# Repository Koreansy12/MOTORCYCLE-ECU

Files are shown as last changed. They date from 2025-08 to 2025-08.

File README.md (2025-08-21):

# 🚀 FCU32 – Fuel Control Unit Based on ESP32

## 📌 Overview  
**FCU32** is an **experimental project** to build a simple **Fuel Control Unit (ECU)** using the **ESP32** platform.  
The main goal is to control a fuel injector based on standard engine sensors (RPM, MAP, TPS, O2, etc.).  

⚠️ **Disclaimer:**  
This project is still **theoretical**. The components and system have been designed and validated on paper, but **not yet fully realized in hardware**. It’s more like a **concept validation** and research documentation.

---

## 🛠️ Main Components
- **ESP32-S3** (main MCU)  
- **MAP + IAT + TPS Sensor** (from MAQS injector system)  
- **O2 Sensor** (Beat FI)  
- **RPM Pickup Sensor**  
- **Injector (Mio J)**  
- **Power Supply & MOSFET Driver** for injector control  

---

## 📊 Planned Features
- Fuel Injection Control via **lookup/VE table**  
- RPM sensing using **interrupts**  
- TPS & MAP input for engine load calculation  
- O2 sensor input for **closed-loop fuel correction** (planned)  
- UART/I2C communication with a **second ESP32-S3** (for display, logging, fuzzy logic)  
- Multitasking support using **FreeRTOS**  

---

## 📂 Project Status
- ✅ RPM sensor tested on ESP32 (MicroPython)  
- ✅ Pinout and main components planned  
- 🟡 Fuel mapping table (draft stage)  
- 🟡 Injector MOSFET driver (design stage)  
- ❌ Full hardware implementation not yet realized  

---

## 🚧 Next Steps
1. Implement fuel mapping → injector duty cycle control  
2. Test MOSFET driver with actual injector  
3. Integrate O2 sensor for closed-loop correction  
4. Optimize multitasking using FreeRTOS  

---

## ⚡ Why FCU32?
Most aftermarket ECUs are:  
- Expensive 💸  
- Closed-source 🔒  
- Not flexible for DIY/research purposes  

FCU32 aims to be **open-source, affordable, and flexible**, making it suitable for electronics/automotive students and hobbyists who want to experiment.

---

## 📜 License
MIT License – free to use, modify, and develop.  
⚠️ **Note:** This is **not a plug-and-play ECU**. Use at your own risk.

---

## 🤝 Contribution
Contributions are welcome! You can help by:  
- Adding MicroPython / C++ code for injector control  
- Designing hardware (driver + protection circuits)  
- Engine simulation (EngineSim, MATLAB, etc.)  
- Testing on real engines (⚠️ do it at your own risk)  

---

## 🔥 Notes
> This component is theoretically right but has not been realized yet.  
> FCU32 is still in the **concept stage**, and this documentation is mainly to track progress and guide future development.

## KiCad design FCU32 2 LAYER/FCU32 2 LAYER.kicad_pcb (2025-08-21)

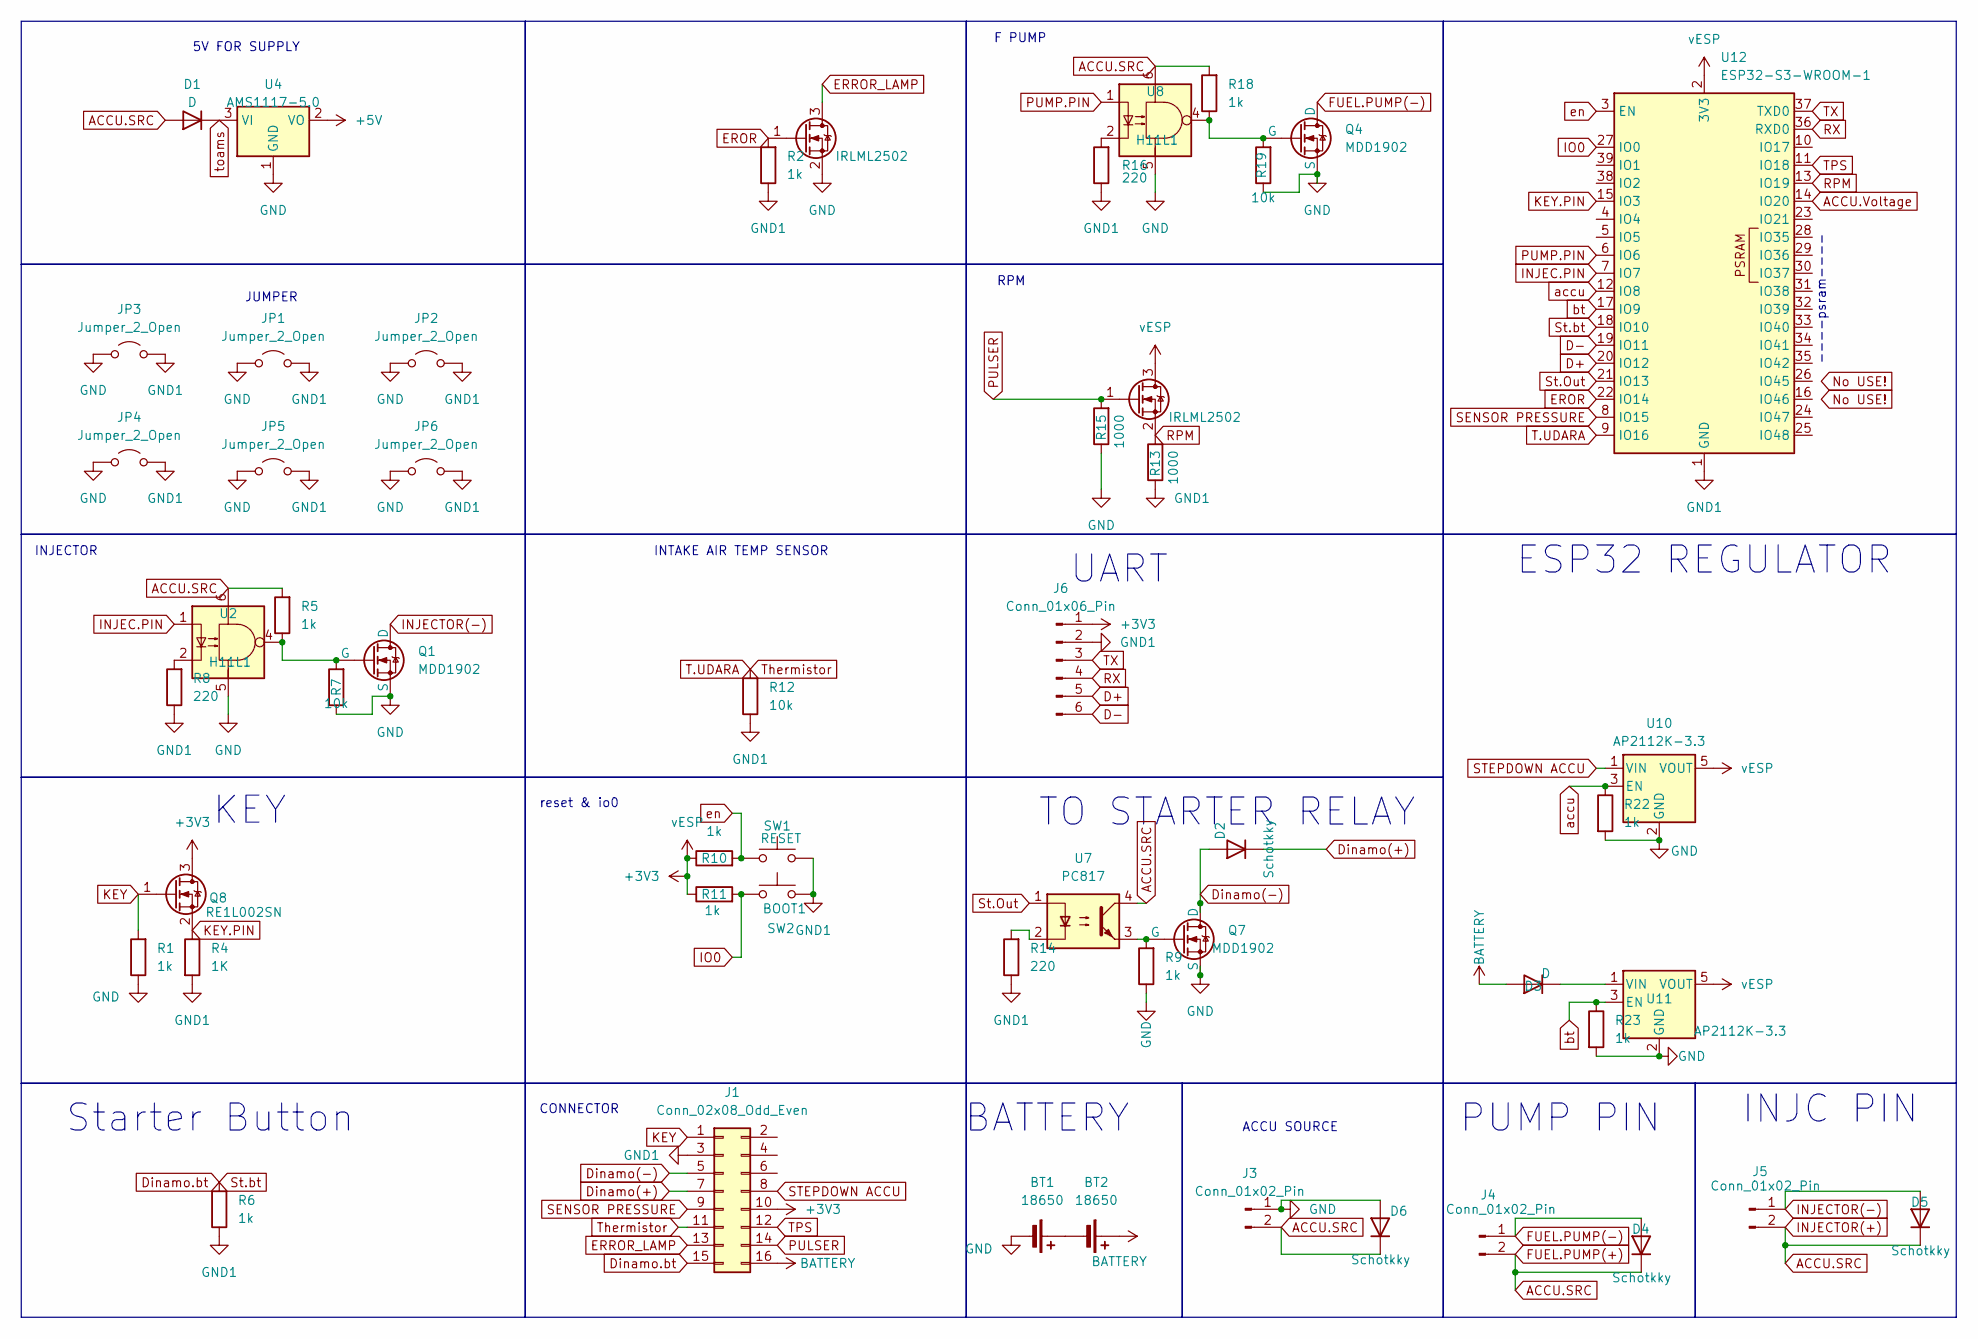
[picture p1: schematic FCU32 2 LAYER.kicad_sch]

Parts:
BT1, BT2: 18650
D1, D3: D; D_SMA
D2, D4, D5, D6: Schotkky; D_SMA
J1: Conn_02x08_Odd_Even; PinHeader_2x08_P2.54mm_Horizontal
J3, J4, J5: Conn_01x02_Pin; AMASS_XT30PW-M_1x02_P2.50mm_Horizontal
J6: Conn_01x06_Pin; PinHeader_1x06_P2.54mm_Horizontal
JP1, JP2, JP3, JP4, JP5, JP6: Jumper_2_Open; SolderJumper-2_P1.3mm_Open_RoundedPad1.0x1.5mm
Q1, Q4, Q7: MDD1902; TO-252-2
Q3, Q5: IRLML2502; SOT-23
Q8: RE1L002SN; SOT-416
R1, R2, R5, R6, R9, R10, R11, R18, R22, R23: 1k; R_1206_3216Metric_Pad1.30x1.75mm_HandSolder
R4: 1K; R_1206_3216Metric_Pad1.30x1.75mm_HandSolder
R7, R12, R19: 10k; R_1206_3216Metric_Pad1.30x1.75mm_HandSolder
R8, R14, R16: 220; R_1206_3216Metric_Pad1.30x1.75mm_HandSolder
R13, R15: 1000; R_1206_3216Metric_Pad1.30x1.75mm_HandSolder
SW1: RESET; SW_PUSH_6mm_H4.3mm
SW2: BOOT1; SW_PUSH_6mm_H4.3mm
U2, U8: H11L1; DIP-6_W7.62mm
U4: AMS1117-5.0; SOT-223-3_TabPin2
U7: PC817; DIP-4_W7.62mm
U10, U11: AP2112K-3.3; SOT-23-5
U12: ESP32-S3-WROOM-1

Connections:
+3V3: J1.10, J6.1, Q5.3 (D), Q8.3 (D), R10.1, R11.1, U10.5 (VOUT), U11.5 (VOUT), U12.2 (3V3)
+5V: U4.2 (VO)
ACCU.SRC: D1.2 (A), D4.1 (K), D5.1 (K), D6.1 (K), J3.2, J4.2, J5.2, R5.2, R18.2, U2.6, U7.4, U8.6
ACCU.Voltage: U12.14 (IO20)
BATTERY: BT2.1 (+), D3.2 (A), J1.16
D+: J6.5, U12.20 (IO12)
D-: J6.6, U12.19 (IO11)
Dinamo(+): D2.1 (K), J1.7
Dinamo(-): D2.2 (A), J1.5, Q7.1 (D)
Dinamo.bt: J1.15, R6.2, U12.18 (IO10)
EROR: Q3.1 (G), R2.2, U12.22 (IO14)
ERROR_LAMP: J1.13, Q3.3 (D)
FUEL.PUMP(-): D4.2 (A), J4.1, Q4.1 (D)
GND: BT1.2 (-), D6.2 (A), J3.1, JP1.1 (A), JP2.1 (A), JP3.1 (A), JP4.1 (A), JP5.1 (A), JP6.1 (A), Q1.3 (S), Q3.2 (S), Q4.3 (S), Q7.3 (S), R1.1, R7.1, R9.1, R15.1, R19.1, R22.2, R23.2, U2.5, U4.1 (GND), U8.5, U10.2 (GND), U11.2 (GND)
GND1: J1.3, J6.2, JP1.2 (B), JP2.2 (B), JP3.2 (B), JP4.2 (B), JP5.2 (B), JP6.2 (B), R2.1, R4.2, R6.1, R8.1, R12.1, R13.1, R14.1, R16.1, SW1.2, SW2.2, U12.1 (GND), U12.40 (GND), U12.41 (GND)
INJEC.PIN: U2.1, U12.7 (IO7)
INJECTOR(-): D5.2 (A), J5.1, Q1.1 (D)
IO0: R11.2, SW2.1, U12.27 (IO0)
KEY: J1.1, Q8.1 (G), R1.2
KEY.PIN: Q8.2 (S), R4.1, U12.15 (IO3)
unnamed: BT1.1 (+), BT2.2 (-)
unnamed: D3.1 (K), U11.1 (VIN)
unnamed: Q1.2 (G), R5.1, R7.2, U2.4
unnamed: Q4.2 (G), R18.1, R19.2, U8.4
unnamed: Q7.2 (G), R9.2, U7.3
unnamed: R8.2, U2.2
unnamed: R14.2, U7.2
unnamed: R16.2, U8.2
PULSER: J1.14, Q5.1 (G), R15.2
PUMP.PIN: U8.1, U12.6 (IO6)
RPM: Q5.2 (S), R13.2, U12.13 (IO19)
RX: J6.4, U12.36 (RXD0)
SENSOR PRESSURE: J1.9, U12.8 (IO15)
STEPDOWN ACCU: J1.8, U10.1 (VIN)
St.Out: U7.1, U12.21 (IO13)
T.UDARA: J1.11, R12.2, U12.9 (IO16)
TPS: J1.12, U12.11 (IO18)
TX: J6.3, U12.37 (TXD0)
accu: R22.1, U10.3 (EN), U12.12 (IO8)
bt: R23.1, U11.3 (EN), U12.17 (IO9)
en: R10.2, SW1.1, U12.3 (EN)
toams: D1.1 (K), U4.3 (VI)

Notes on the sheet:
PUMP PIN
reset & io0
BATTERY
UART
F PUMP
ACCU SOURCE
----psram----
INJC PIN
TO STARTER RELAY
RPM
JUMPER
5V FOR SUPPLY
INTAKE AIR TEMP SENSOR
CONNECTOR
INJECTOR
Starter Button
ESP32 REGULATOR
KEY

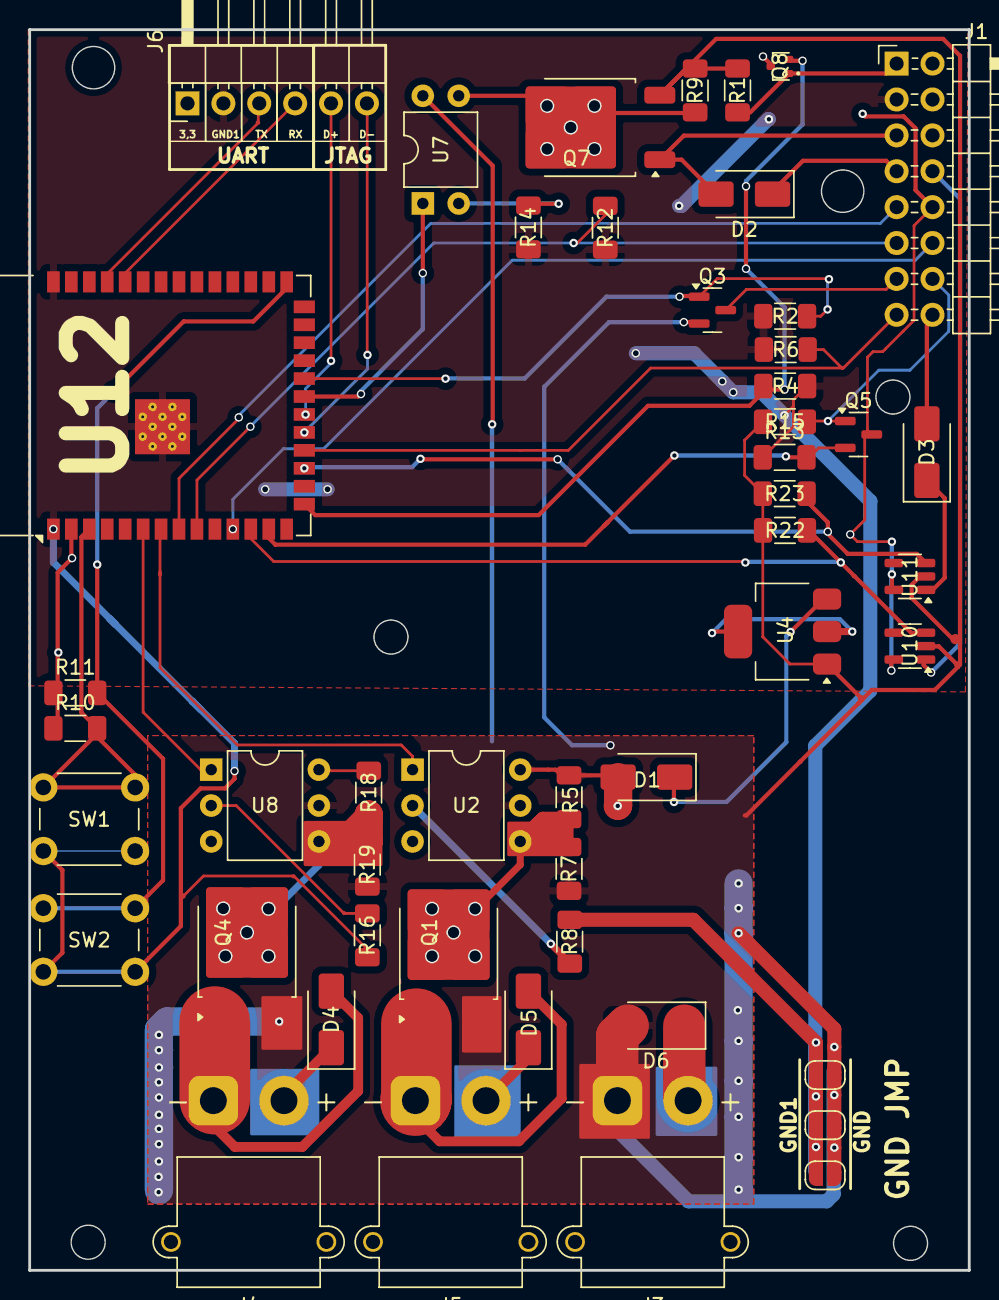
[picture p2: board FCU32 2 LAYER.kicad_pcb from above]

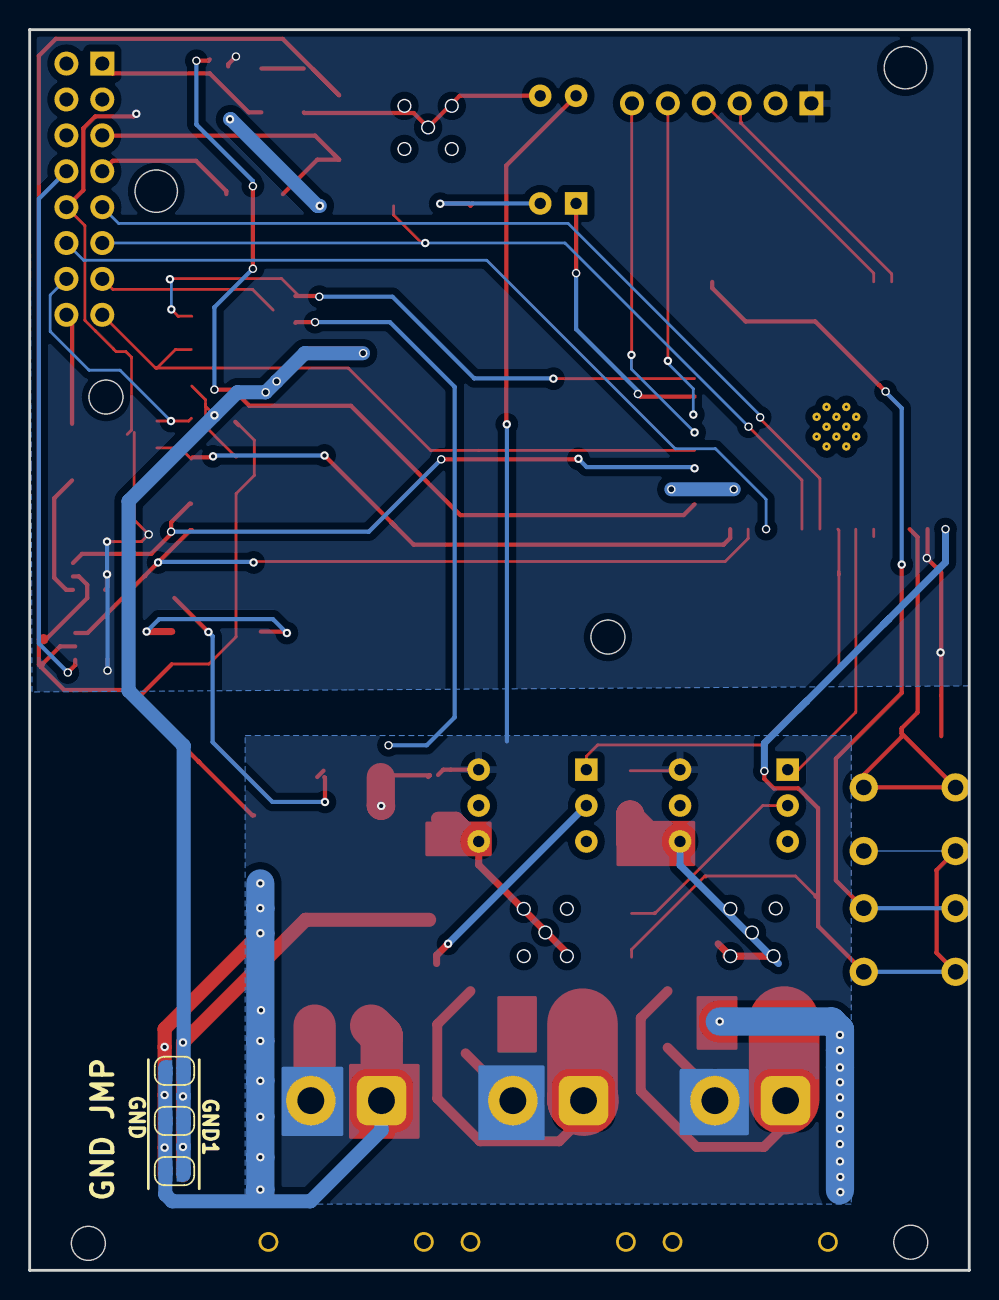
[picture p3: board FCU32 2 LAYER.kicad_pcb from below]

Board: 2 copper layers, 66.5 x 87.8 mm, 51 parts (3 on the bottom side), 39 nets.
